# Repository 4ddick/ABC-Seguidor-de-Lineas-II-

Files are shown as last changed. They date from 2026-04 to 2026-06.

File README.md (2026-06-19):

Seguidor-de-linea-ABCII
Seguidor de linea modelo ABC (versión.II)

Durante el presente año, los integrantes del equipo "ABC" han asumido el compromiso de desarrollar un nuevo diseño del proyecto previo denominado "Robot seguidor de línea ABC I". El rediseño contempla modificaciones estructurales y funcionales orientadas a optimizar el desempeño del sistema, incrementar la precisión en el seguimiento de trayectorias y mejorar la interacción con el usuario.

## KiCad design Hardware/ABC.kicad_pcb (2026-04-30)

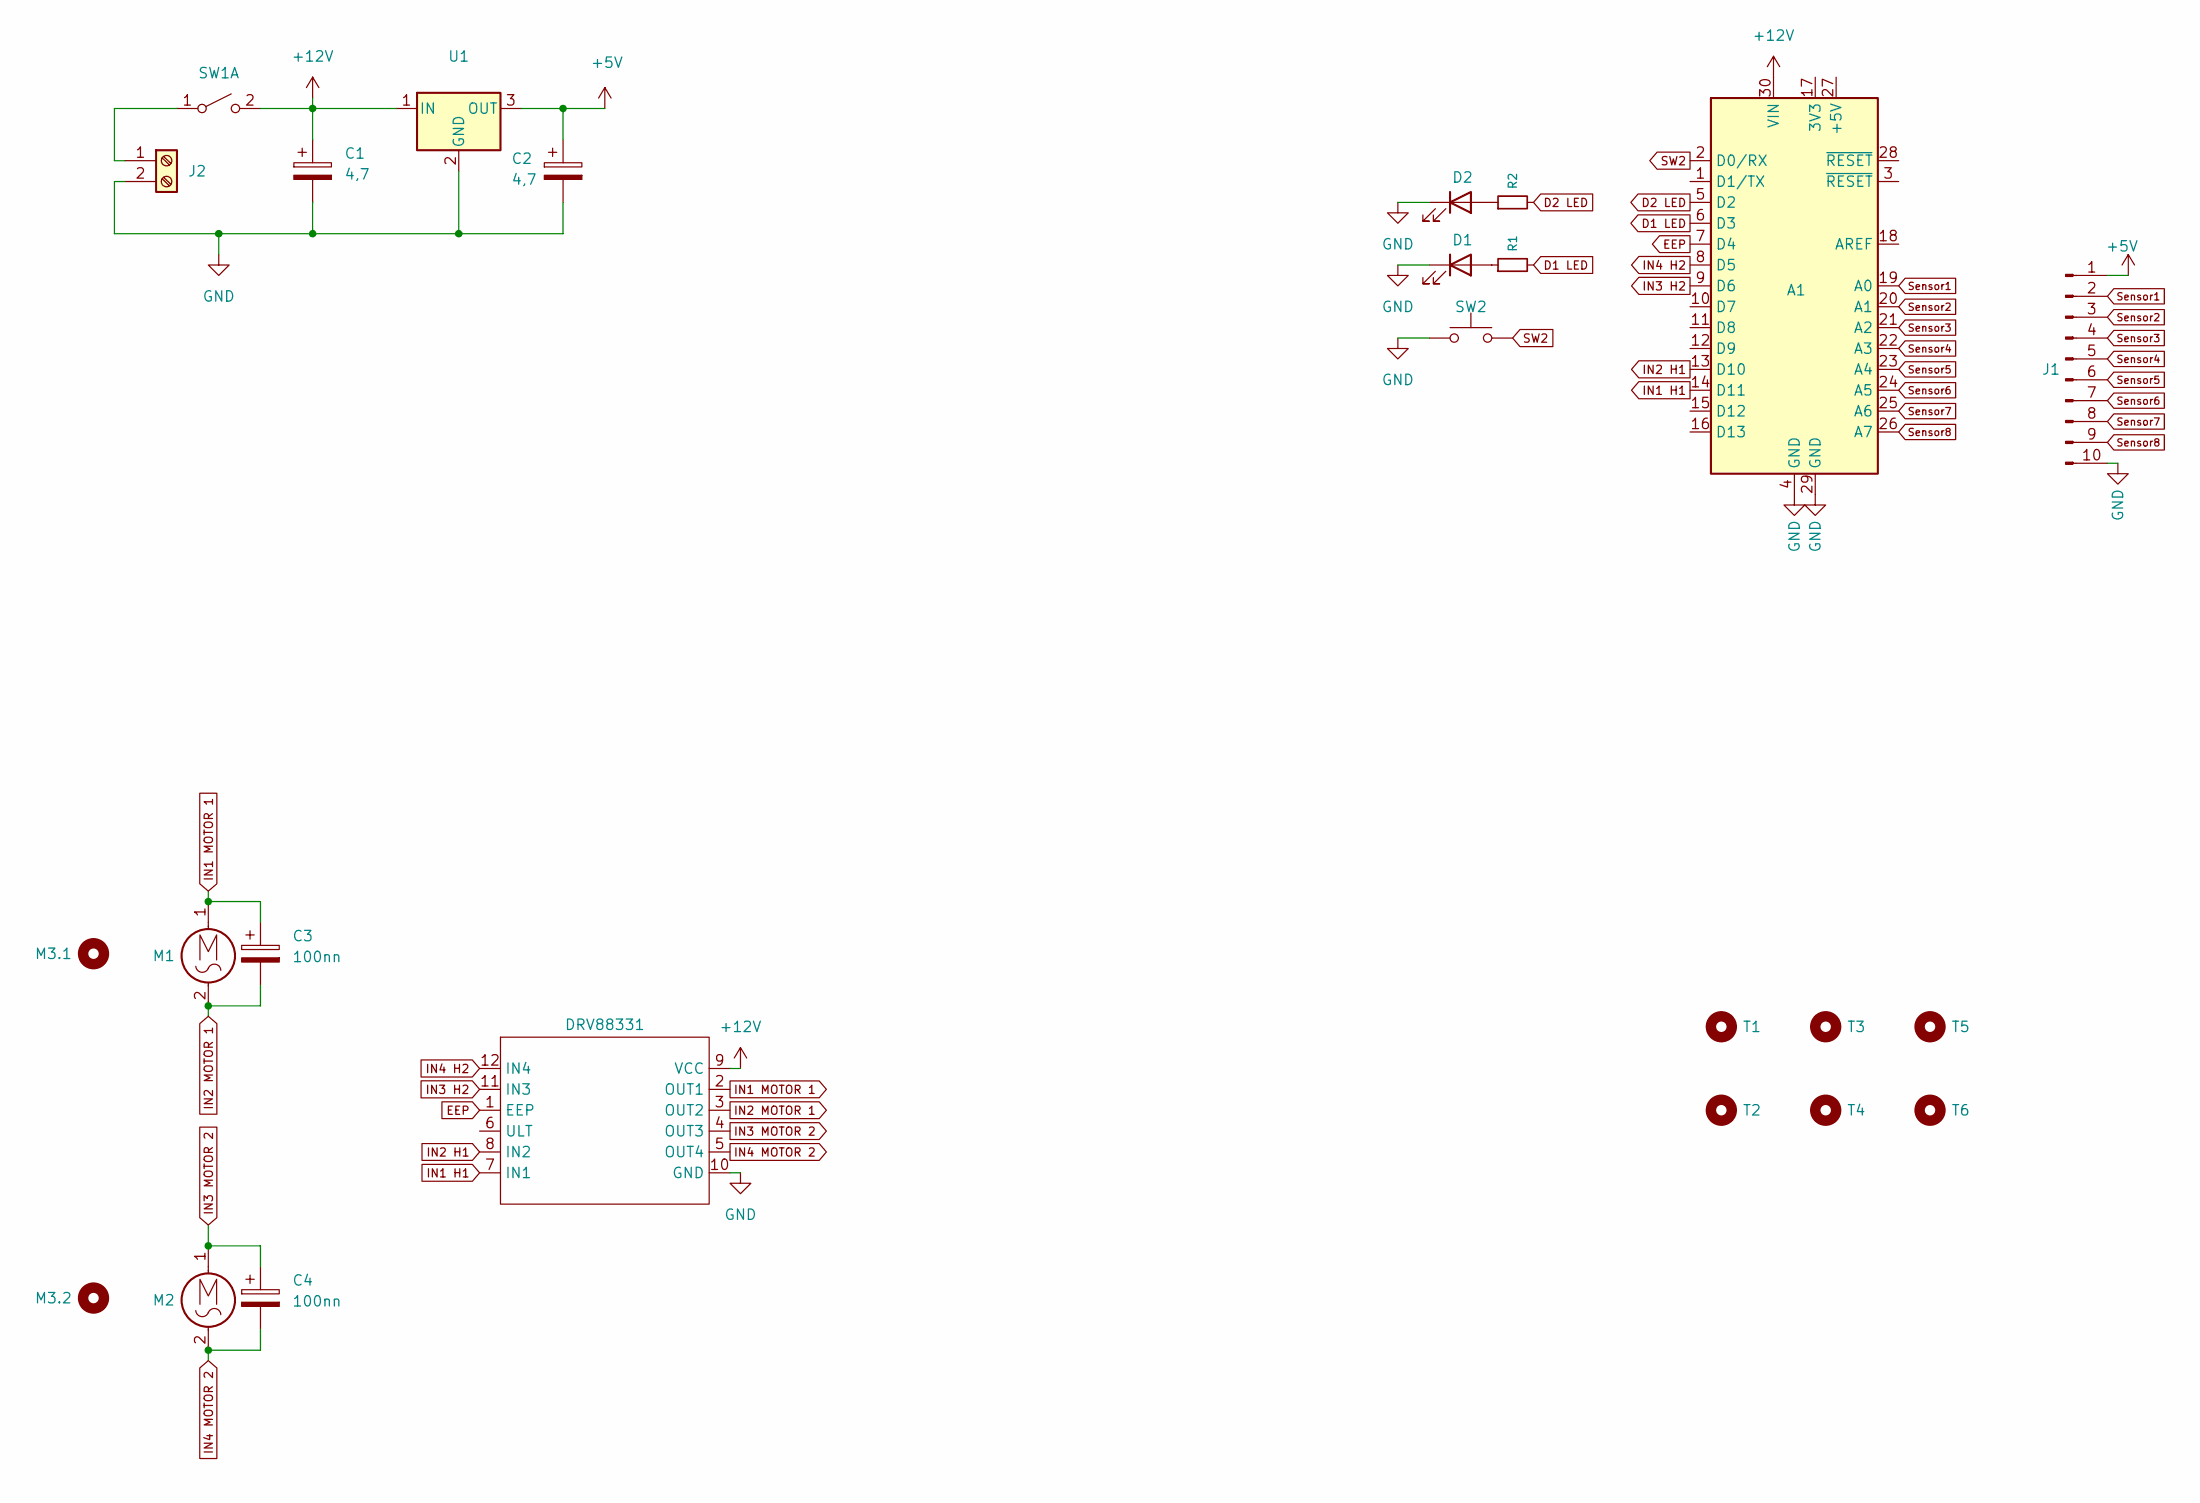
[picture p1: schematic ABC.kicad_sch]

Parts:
A1: Arduino_Nano_v2.x; Arduino_Nano
C1, C2: 4,7; CP_Radial_D6.3mm_P2.50mm
C3, C4: 100nn; C_Disc_D5.0mm_W2.5mm_P5.00mm
D1, D2: LED; LED_D5.0mm
DRV88331: PUENTE H1; DRV8833_MODULE
J1: Conn_01x10_Pin; PinHeader_1x10_P2.54mm_Vertical
J2: XT30AWM
M1, M2: Motor_AC; PinHeader_1x02_P2.54mm_Vertical
M3.1, M3.2: Mounting_Hole; Pololu_Micro_Bracket_Wheel_42mm
R1, R2: R_Small; R_Axial_DIN0207_L6.3mm_D2.5mm_P7.62mm_Horizontal
SW1: SW_DPST_x2; TerminalBlock_MaiXu_MX126-5.0-03P_1x03_P5.00mm
SW2: SW_PUSH; Button
T1, T2, T3, T4, T5, T6: Mounting_Hole; MountingHole_3.2mm_M3
U1: L7805; TO-220-3_Vertical

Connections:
+5V: C2.1, J1.1, U1.3 (OUT)
+12V: A1.30 (VIN), C1.1, DRV88331.9 (VCC), SW1.2 (B), SW1.3 (A), U1.1 (IN)
D1 LED: A1.6 (D3), R1.2
D2 LED: A1.5 (D2), R2.2
EEP: A1.7 (D4), DRV88331.1 (EEP)
GND: A1.4 (GND), A1.29 (GND), C1.2, C2.2, D1.1 (K), D2.1 (K), DRV88331.10 (GND), J1.10, J2.2, SW2.1, U1.2 (GND)
IN1 H1: A1.14 (D11), DRV88331.7 (IN1)
IN1 MOTOR 1: C3.1, DRV88331.2 (OUT1), M1.1
IN2 H1: A1.13 (D10), DRV88331.8 (IN2)
IN2 MOTOR 1: C3.2, DRV88331.3 (OUT2), M1.2
IN3 H2: A1.9 (D6), DRV88331.11 (IN3)
IN3 MOTOR 2: C4.1, DRV88331.4 (OUT3), M2.1
IN4 H2: A1.8 (D5), DRV88331.12 (IN4)
IN4 MOTOR 2: C4.2, DRV88331.5 (OUT4), M2.2
unnamed: D1.2 (A), R1.1
unnamed: D2.2 (A), R2.1
unnamed: J2.1, SW1.1 (A)
SW2: A1.2 (D0/RX), SW2.2
Sensor1: A1.19 (A0), J1.2
Sensor2: A1.20 (A1), J1.3
Sensor3: A1.21 (A2), J1.4
Sensor4: A1.22 (A3), J1.5
Sensor5: A1.23 (A4), J1.6
Sensor6: A1.24 (A5), J1.7
Sensor7: A1.25 (A6), J1.8
Sensor8: A1.26 (A7), J1.9

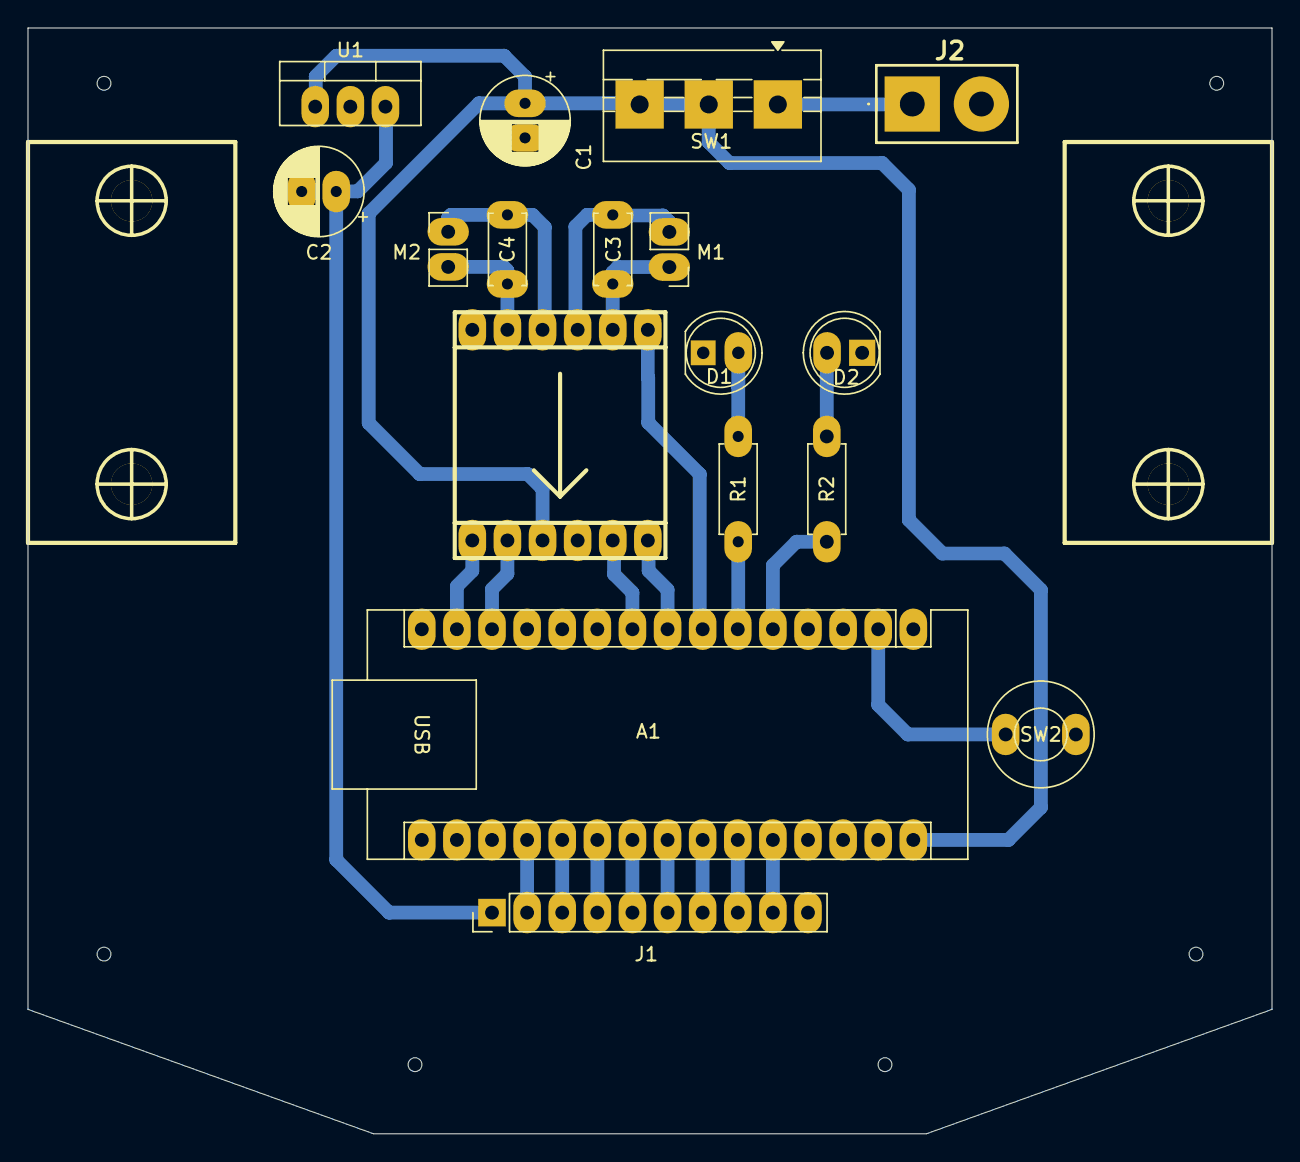
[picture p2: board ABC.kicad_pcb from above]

Board: 2 copper layers, 90.0 x 80.0 mm, 25 parts (0 on the bottom side), 26 nets.

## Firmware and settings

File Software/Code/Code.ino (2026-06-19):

#include <Arduino.h>
#include <QTRSensors.h>

//Pines de motores y calibración
#define BOTTOM 12
#define LED_CAL 2
#define PinA1 10
#define PinB1 5
#define PinA2 11
#define PinB2 6

//Placa de sensores
QTRSensors qtr;
const uint8_t SensorCount = 8;
uint16_t sensorValues [SensorCount];

// POSICIÓN 
int pos = 0;
int errorLast = 0;
int sumap = 0;
int suma = 0;

// PID (REVISAR) 
float kp = 0.7;
float kd = 4.0;
float setpoint = 2500;
int correccion = 0;
int baseSpeed = 130;

//Control motores
class Motor {
    private:
    int PinA;
    int PinB;

    public:
    Motor (int _PinA,int _PinB): PinA(_PinA),PinB(_PinB) {}
    void begin(){
        pinMode (PinA, OUTPUT);
        pinMode (PinB, OUTPUT);
        digitalWrite (PinA, HIGH);
        digitalWrite (PinA, HIGH);
    }
    void setSpeed(int speed){
        speed = constrain(speed, -255, 255);
        if (speed > 0){ 
        digitalWrite(PinA, HIGH);
        analogWrite (PinB, 255 -speed);
        } else if (speed < 0){
            analogWrite (PinA, 255 +speed);
            digitalWrite(PinB, HIGH);
        } else {
            digitalWrite (PinA, HIGH);
            digitalWrite (PinB, HIGH);
        }
    }
} ;

Motor M1(PinA1, PinB1);
Motor M2(PinA2, PinB2);

void setup(){
  Serial.begin(115200);
  pinMode(BOTTOM, INPUT_PULLUP);
  pinMode(LED_CAL, OUTPUT);

  M1.begin();   // Iniciar motor 1
  M2.begin();   // Inicia motor 2
  
  qtr.setTypeAnalog();
  uint8_t sensorPins[]={A0,A1,A2,A3,A4,A5,A6,A7};
  qtr.setSensorPins(sensorPins, SensorCount);
  while(!digitalRead(BOTTOM)){}
  digitalWrite (LED_CAL, HIGH);
  for (uint16_t i = 0; i < 400; i++){
    qtr.calibrate();
  }
  digitalWrite(LED_CAL, LOW);
}

void loop()
{
  // read calibrated sensor values and obtain a measure of the line position
  // from 0 to 5000 (for a white line, use readLineWhite() instead)
  uint16_t pos = qtr.readLineBlack(sensorValues);
   //PD
  float error    = (float)pos - setpoint;
  float derivada = error - errorLast;
  correccion     = (error * kp) + (derivada * kd);
  errorLast      = error;

  M1.setSpeed(constrain(baseSpeed - correccion, -255, 255));
  M2.setSpeed(constrain(baseSpeed + correccion, -255, 255));

  for (uint8_t i = 0; i < SensorCount; i++)
  {
    Serial.print(sensorValues[i]);
    Serial.print('\t');
  }
  Serial.println(pos);

  delay(250);
}
